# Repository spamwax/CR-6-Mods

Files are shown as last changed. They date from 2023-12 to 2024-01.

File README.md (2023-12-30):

# CR-6-Mods
Guides for fixing failures of "3D Printing Evangelist" company

# WARNING/DISCLAIMER

## By using the information provided in this repository, you acknowledge that you have read & fully understood the following:

None of the authors of these guides assume responsibility for any damage, harm, injury, loss of money/goods and loss of life that may be caused as a result of using the information provided in this repository.

Proceed with caution, any  modifications and tinkering of mechanical and/or electronic components of your printer is risky & can cause issues mentioned above (including but not limited to your printer catching fire).

Applying the mods listed here is, very likely, going to void any warranty your printer may still have.

# Mods

## BL Touch (say goodbye to the plague that was [claimed to be "better"](https://www.kickstarter.com/projects/3dprintmill/creality-cr-6-se-leveling-free-diy-3d-printer-kit/faqs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))
- [Add BL Touch](./BL%20Touch/Adding%20"BL%20Touch"%20as%20probe%20and%20Z%20end-stop.md) to CR-6

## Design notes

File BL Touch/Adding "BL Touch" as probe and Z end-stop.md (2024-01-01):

I am using Klipper as the firmware of my printer.

Look at [Klipper's documentation](https://www.klipper3d.org) and [this repository](https://github.com/KoenVanduffel/CR-6_Klipper) for instruction on how to set the firmware for CR-6.
My mainboard is _Creality 4.5.2_, other mainboards are going to have different pin names.

I found _Creality 4.5.2_'s pin names from [here](https://github.com/CR6Community/Marlin/blob/extui/Marlin/src/pins/stm32f1/pins_CREALITY_V45x.h) and [here](https://github.com/CR6Community/Marlin/blob/extui/Marlin/src/pins/stm32f1/pins_CREALITY_V452.h).

## Tools
These are the main tools and supplies **I** used, you don't need everything listed here to make this mod work. I'd say the bare minimum is having access to a 3-pin JST connector.

- [Crimping tool and JST/Dupoint connectors](https://www.amazon.com/dp/B0BJZN4KD7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)
- [Wire Stripper](https://www.amazon.com/dp/B097SZ1F7W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)
- [Heat shrink wraps](https://www.amazon.com/dp/B072PCQ2LW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)
- [AWG24 Wires](https://www.amazon.com/dp/B089D13Y1N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)
- [Soldering Iron](https://www.amazon.com/gp/product/B00ANZRT4M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) and [Solder](https://www.amazon.com/gp/product/B00068IJWC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)
- [Multimeter](https://www.amazon.com/gp/product/B000EVYGZA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)
- [BL Touch](https://www.amazon.com/dp/B076PQG1FF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) (duh!)

1. Open the optical sensor and cut its wires as close to sensor as you can.
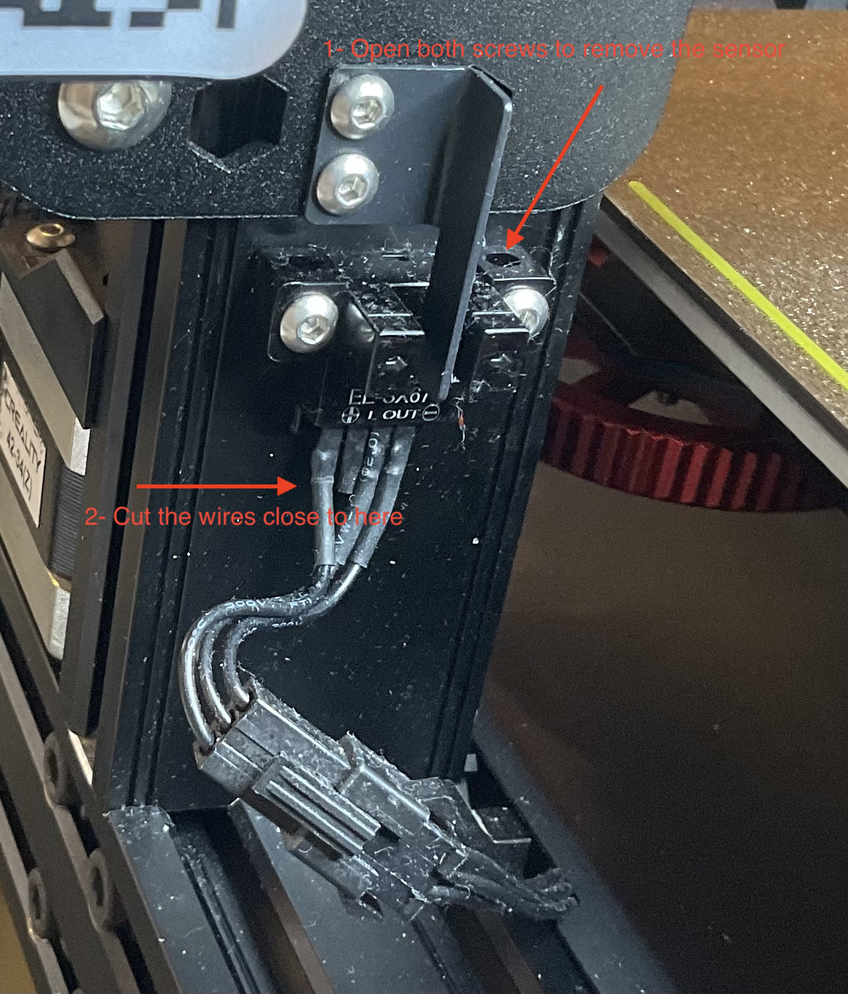
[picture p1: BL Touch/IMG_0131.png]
Optical sensor

2. Using the following picture, extend the wires from the from the optical sensor's JST connector and connect it to the BL Touch servo wires: looking at the JST connector with its tab facing you
    - the left wire should be connected to BL Touch's *5V* (red wire)
    - the middle wire should be connected to BL Touch's *servo* (orange wire)
    - the right wire should be connected to BL Touch's *ground* (brown wire)
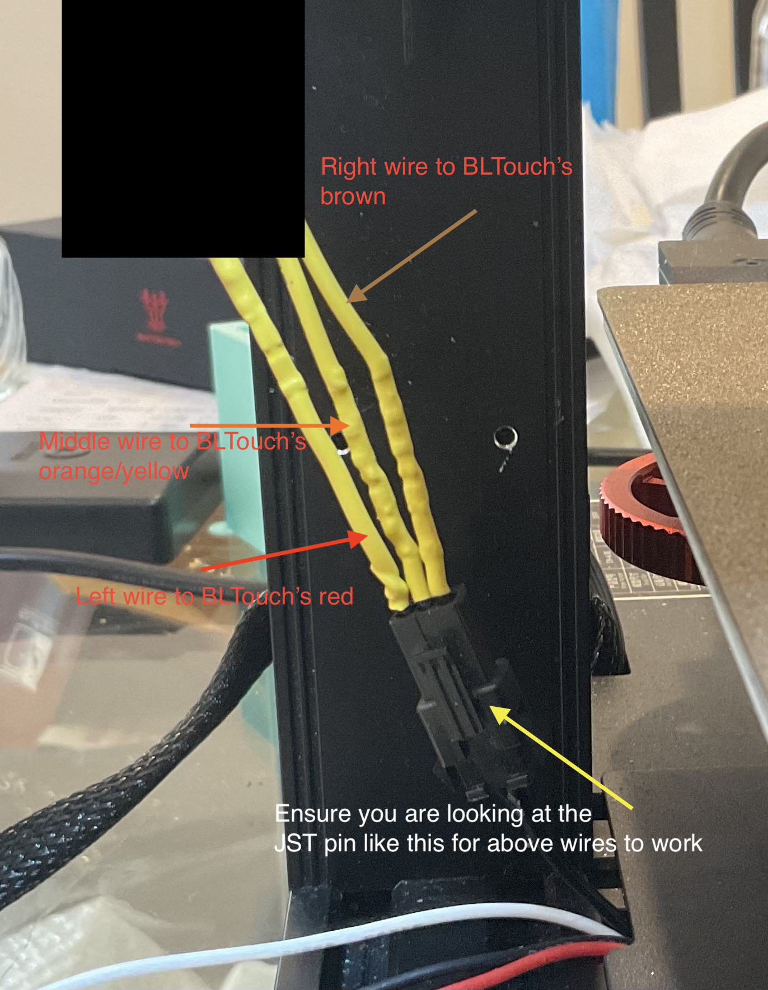
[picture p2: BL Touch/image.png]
Optical sensor rewiring

3. Cut 3 wires, preferably different colors, with an approximate length of 40*cm* to 50*cm*. I used red, black and white. Then connect them to a female JST XH-3Y pin. You will need [the crimping tool](https://www.amazon.com/dp/B0BJZN4KD7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) for this step.
4. Open the mainboard's cover to access it, and conect the female JST connector from step 3 to the mainboard header labled **J3**. In my case, the red wire is connected to top pin (3.3V) on J3, the black is connected to middle pin (ground) and the white is connected to bottom pin (signal). You will not use the red wire for BL Touch, I did it for future just in case if I ever needed a 3.3V line.
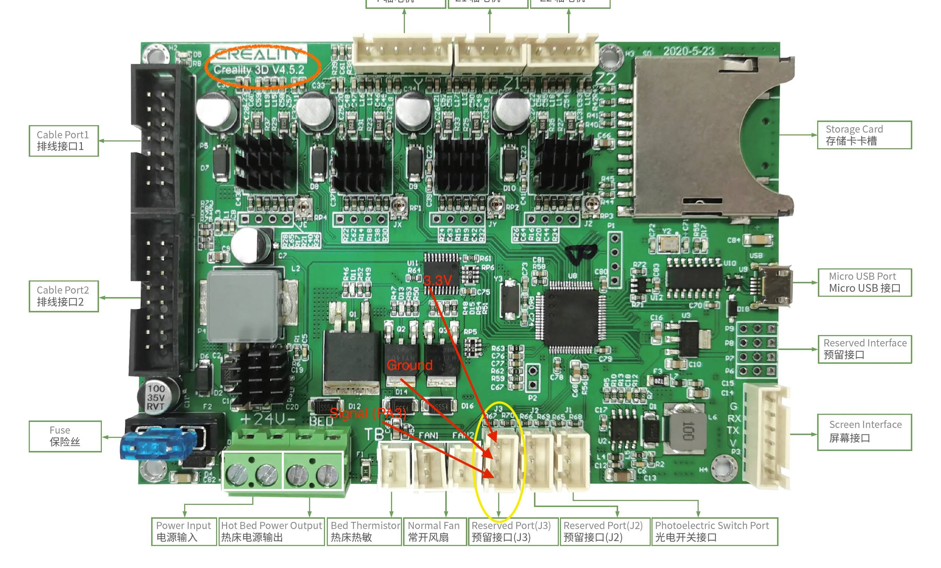
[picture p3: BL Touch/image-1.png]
mainboard J3

This is my female JST XH-3Y connector with 3 different color wires:
6. Carefully route the 3 wires through the same hole that the old/removed optical sensor cables are using.
7. The other end of the wires (from step 3) will be connected to BL Touch's probe signal:
    - Black wire from BL Touch to the ground pin of mainboard's J3 connector (in my case also black)
    - White wire from BL Touch to the signal pin of mainboard's J3 connector (in my case also white)
    - If like me, you also connected the 3.3V pin of mainboard's J3 connector to a wire, make sure it is fully insulated.
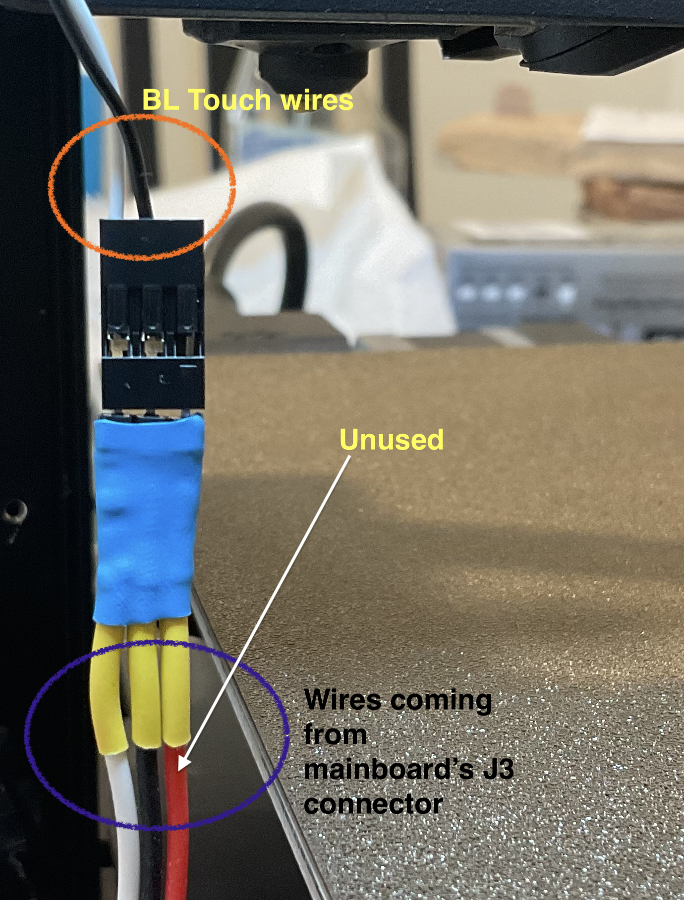
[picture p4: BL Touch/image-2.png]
BLTouch signal
    

## Klipper config

The optical sensor was originally connected to `PC6` of MCU, and J3 connector's signal pin on mainboard is connected to `PA3` of MCU.
Therefore in your `printer.cfg` file of Klipper you need to have the following minimum setup:

```ini
[bltouch]
sensor_pin: PA3 # J3 connector's signal pin
control_pin: PC6 # Original optical sensor pin
```

Adjust the other options of `bltouch` section in `printer.cfg` file based on how you will mount the BL Touch to the X-carriage. You want to fully understand & follow the excellent guides in Klipper documentation for [Bed Leveling](https://www.klipper3d.org/Bed_Level.html) and [BL Touch setup](https://www.klipper3d.org/BLTouch.html).

I mounted mine using a combination of 3D printed part & some metallic parts I had from my monitor stand!
bltouch mount
The CAD files I used in the above setup: [X-Carriage Mount](../resources/BLTouchCarriage-Mount.step) and [BL Touch Mount](../resources/BLTouch-Mount.step)

## Acknowledgement

[Q_not](https://www.reddit.com/user/Q_not/) was instrumental in [figuring out](https://www.reddit.com/r/CR6/comments/18s6fkv/comment/kf62rpf/?utm_source=share&utm_medium=web2x&context=3)
 the characteristics of *reserved* pins (J2/J3) on the mainboard.

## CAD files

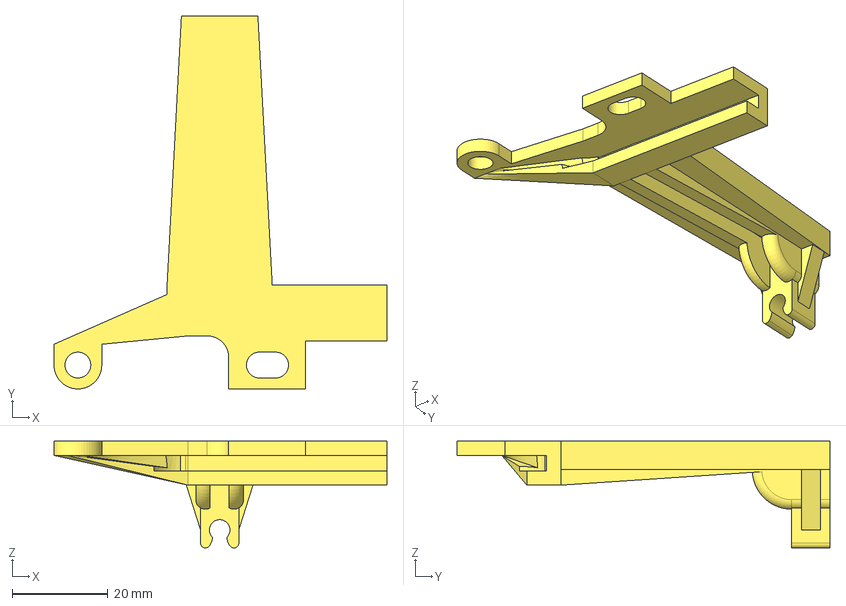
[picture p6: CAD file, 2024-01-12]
resources/PTFE-Retainer.step
69.7 x 78.0 x 22.4 mm

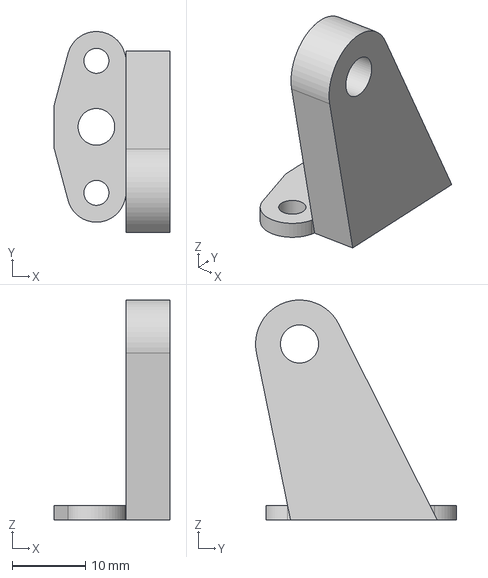
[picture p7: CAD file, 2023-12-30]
resources/BLTouch-Mount.step
15.7 x 27.4 x 30.0 mm

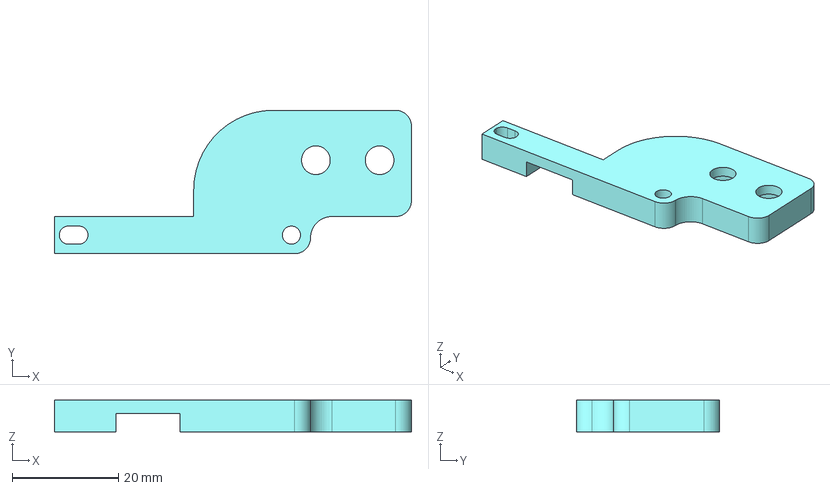
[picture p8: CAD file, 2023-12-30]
resources/BLTouchCarriage-Mount.step
67.2 x 27.0 x 6.00 mm

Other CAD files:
resources/PTFE-Retainer.stl

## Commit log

2023-12-30 Initial commit for BL Touch mod
    [BLTouchCarriage-Mount.step]
2023-12-30 Add schematics of the daughter board
2023-12-30 Update Adding "BL Touch" as probe and Z end-stop.md
2023-12-30 Add BLTouch-Mount.step
    [BLTouch-Mount.step]
2023-12-30 Fix the link to my custom BL Touch Mount
2023-12-30 Improve wiring instructions.
2024-01-01 Add a picture for female JST XH-3Y connector
2024-01-12 Add files via upload
    Add PTFE retainer CAD models
    [PTFE-Retainer.step, PTFE-Retainer.stl]
